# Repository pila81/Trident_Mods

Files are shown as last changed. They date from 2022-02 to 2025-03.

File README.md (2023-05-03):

# Trident Mods

Some modifications and add-ons for the Voron Trident.  

[**AB Stepper Mounts Pin Bearing**](AB_Stepper_Mounts_Pin_Bearing/)  
Trident AB stepper mounts using pins for the idler assemblies and bearings to support the stepper shafts.
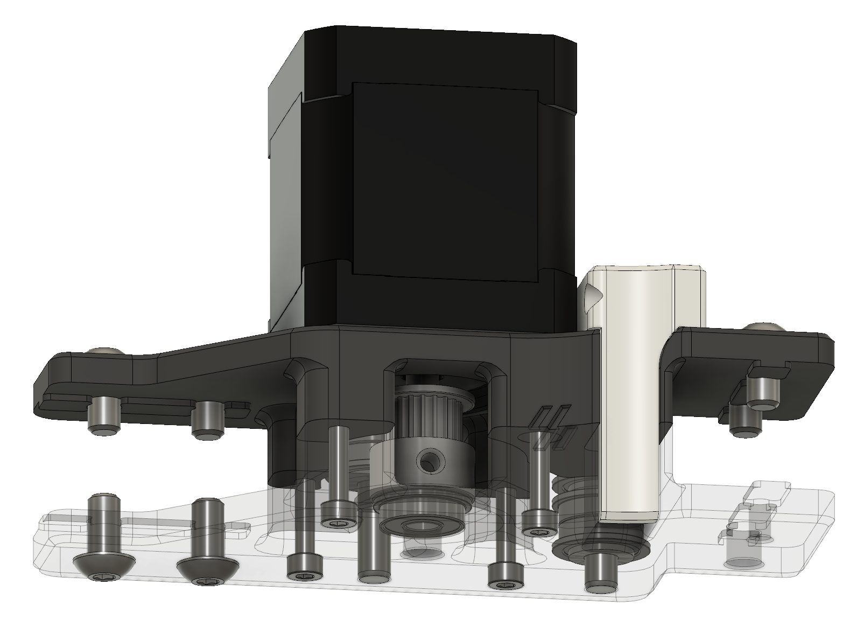
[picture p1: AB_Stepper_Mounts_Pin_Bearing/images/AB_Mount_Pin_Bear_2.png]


[**Idlers Tensioners Aligned**](Idlers_Tensioners_Aligned/)  
Trident front idlers with tensioners aligned to bearings.  
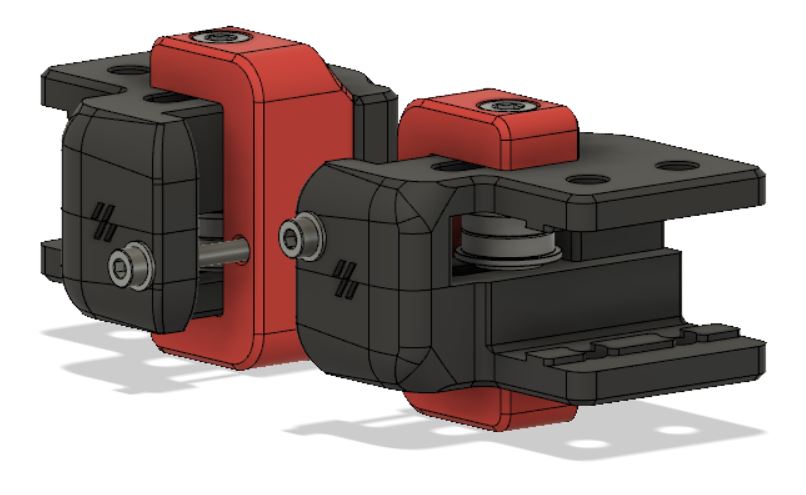
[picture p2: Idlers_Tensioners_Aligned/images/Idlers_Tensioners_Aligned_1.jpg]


[**Exhaust HEPA Filter**](Exhaust_HEPA_Filter/)  
HEPA filter mount for the original exhaust housing.  
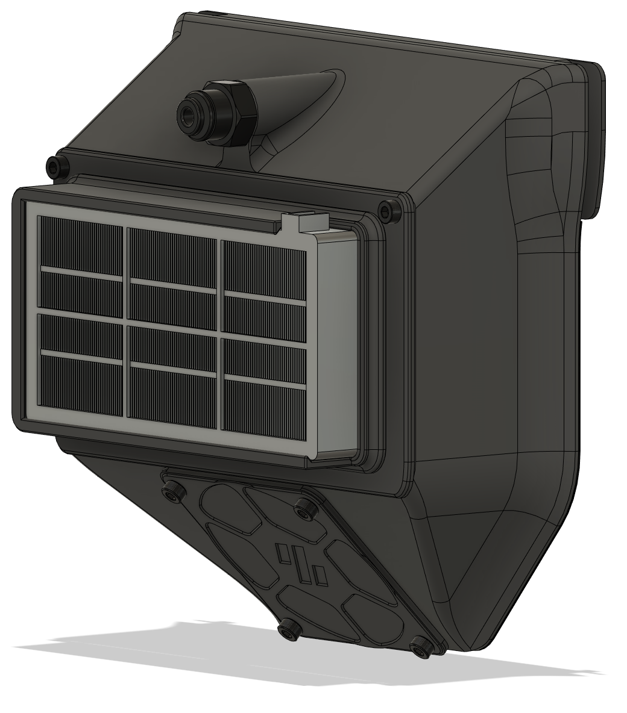
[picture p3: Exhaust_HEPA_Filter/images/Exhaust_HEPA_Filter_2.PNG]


[**Small Exhaust HEPA Filter**](Exhaust_HEPA_Filter_Small/)  
Smaller exhaust housing with HEPA filter mount.  
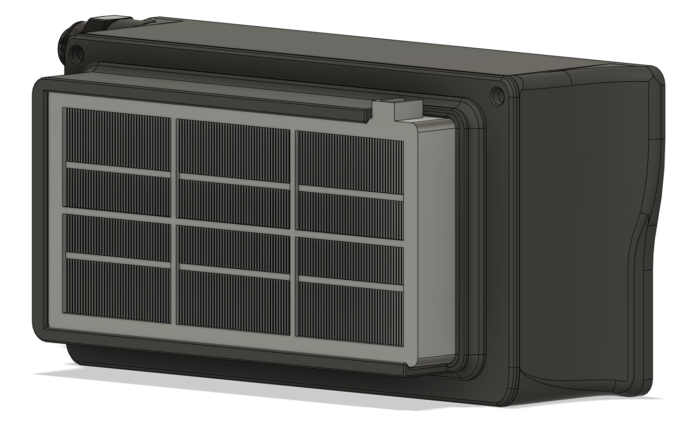
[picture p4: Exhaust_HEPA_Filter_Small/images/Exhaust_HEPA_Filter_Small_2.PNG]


[**Blind Joint Corner Plug**](Blind_Joint_Corner_Plug/)  
Covers the blind joint holes in the top corners of the 2020 extrusions.  
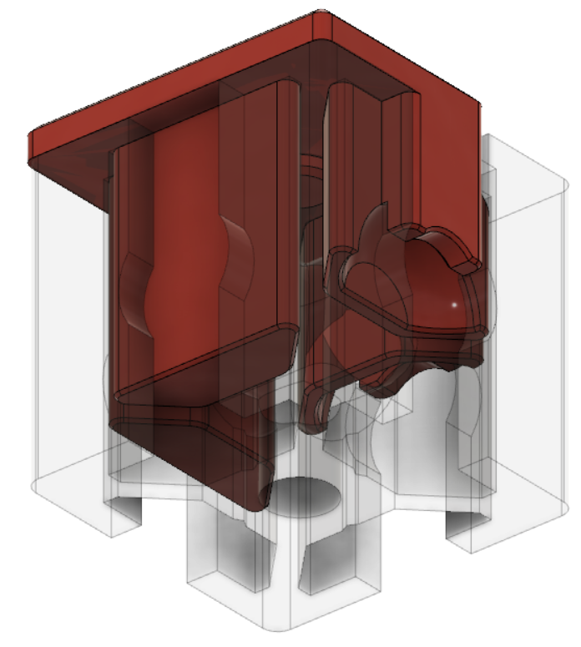
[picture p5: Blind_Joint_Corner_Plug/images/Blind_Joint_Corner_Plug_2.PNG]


[**DIN Rail ZIP Mount**](DIN_Rail_ZIP_Mount/)  
Clip-on DIN rail mount for zip ties/tie wraps.  
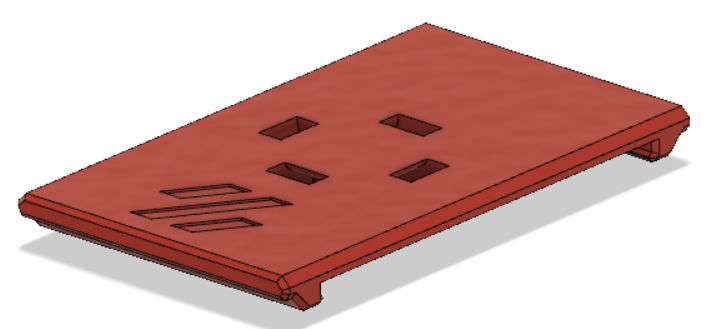
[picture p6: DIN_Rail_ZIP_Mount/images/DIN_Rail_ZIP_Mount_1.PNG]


[**Microfit_2020_Mount_1x2**](Microfit_2020_Mount_1x2/)  
A mount for attaching a 1x2 Microfit plug to a 2020 extrusion.  
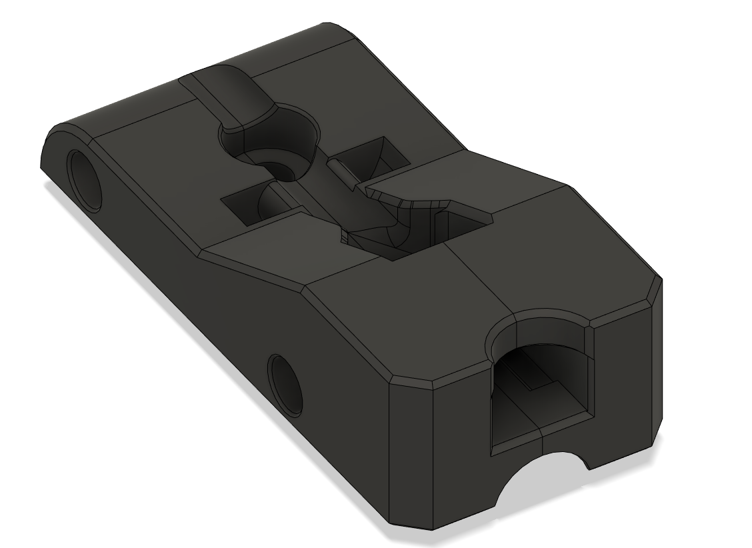
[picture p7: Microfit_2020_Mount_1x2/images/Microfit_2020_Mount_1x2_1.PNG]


[**Z Carriages FLEX**](Z_Carriages_FLEX/)  
Z carriages using a compliant spring mechanism to cope with leadscrew wobble.  
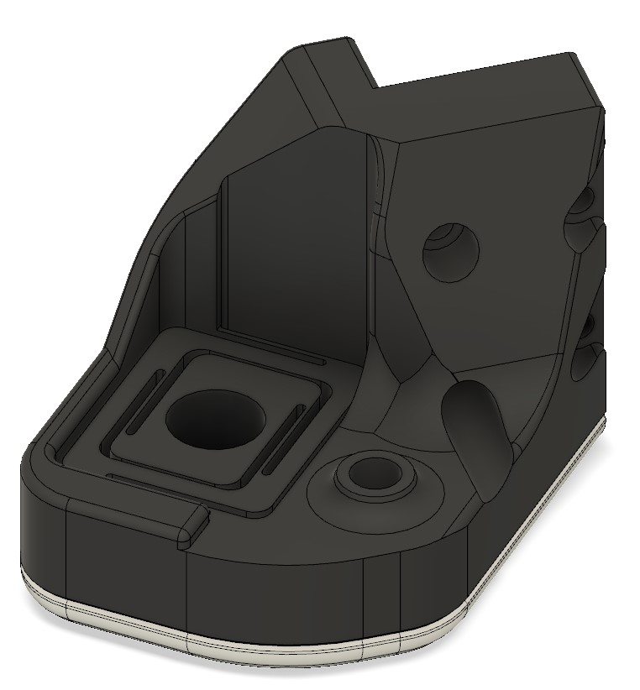
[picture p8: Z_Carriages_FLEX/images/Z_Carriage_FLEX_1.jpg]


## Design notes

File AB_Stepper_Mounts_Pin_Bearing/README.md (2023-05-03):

# AB Stepper Mounts Pin Bearing

**Trident AB Stepper Mounts using pins and bearings**

Trident AB stepper mounts using 5x30 mm pins for the idler assemblies and F695 bearings to support the stepper shafts.

Disclaimer: Only tested this on my printer, use at your own risk.

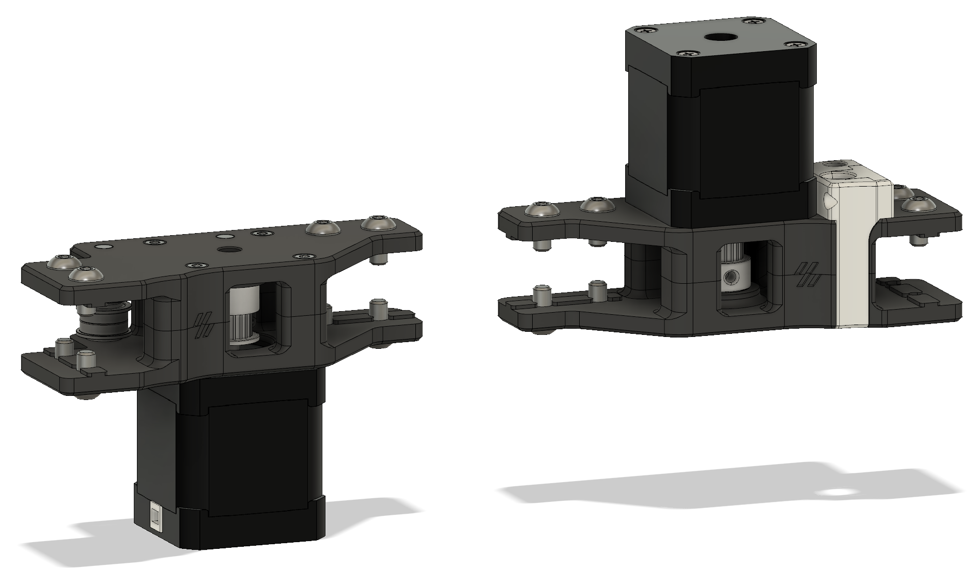
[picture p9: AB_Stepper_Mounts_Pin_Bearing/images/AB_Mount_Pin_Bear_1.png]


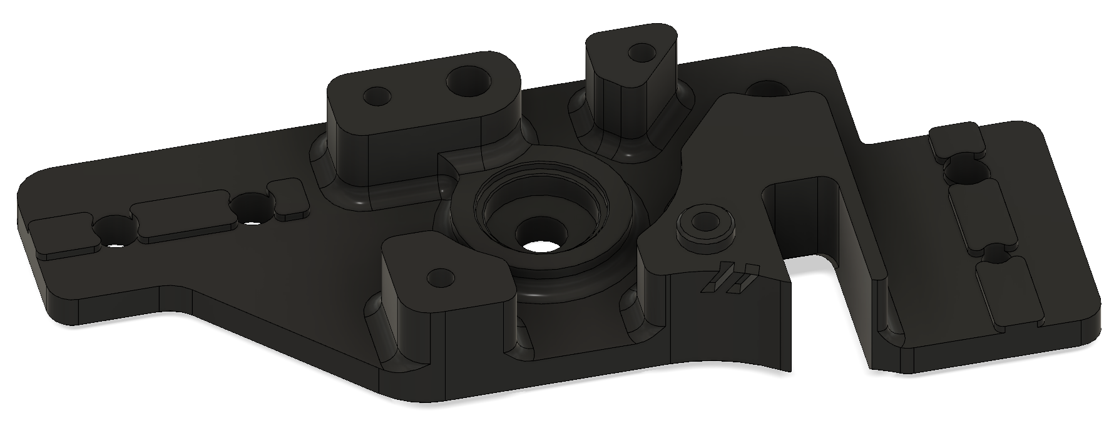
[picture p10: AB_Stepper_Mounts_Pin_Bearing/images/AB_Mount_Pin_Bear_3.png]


Credits for the original stepper mount design go to the Voron team 
https://vorondesign.com/

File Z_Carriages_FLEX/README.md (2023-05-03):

# Z Carriages FLEX

**Trident Z carriages with a printed compliant spring mechanism**

Trident Z carriages with a printed compliant spring mechanism to allow for some leadscrew wobble. 
Top leadscrew mounts (with F688 bearings) are optional, but Z is more accurate with them in my case.
Inspired by ortho-planar spring behavior studies.

2 heatset inserts go into the bottom of each carriage. The leadscrew nut is attached using 2 M3x8 screws with the spacer in between.

Disclaimer: Only tested this on my printer, use at your own risk.


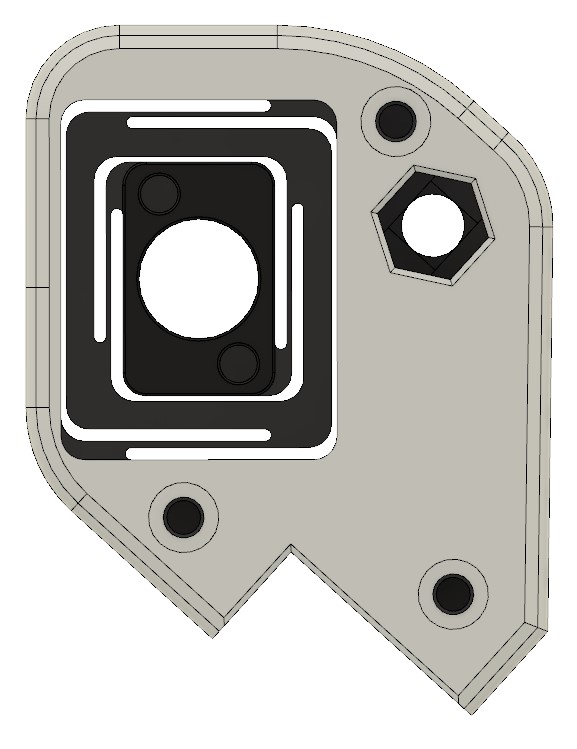
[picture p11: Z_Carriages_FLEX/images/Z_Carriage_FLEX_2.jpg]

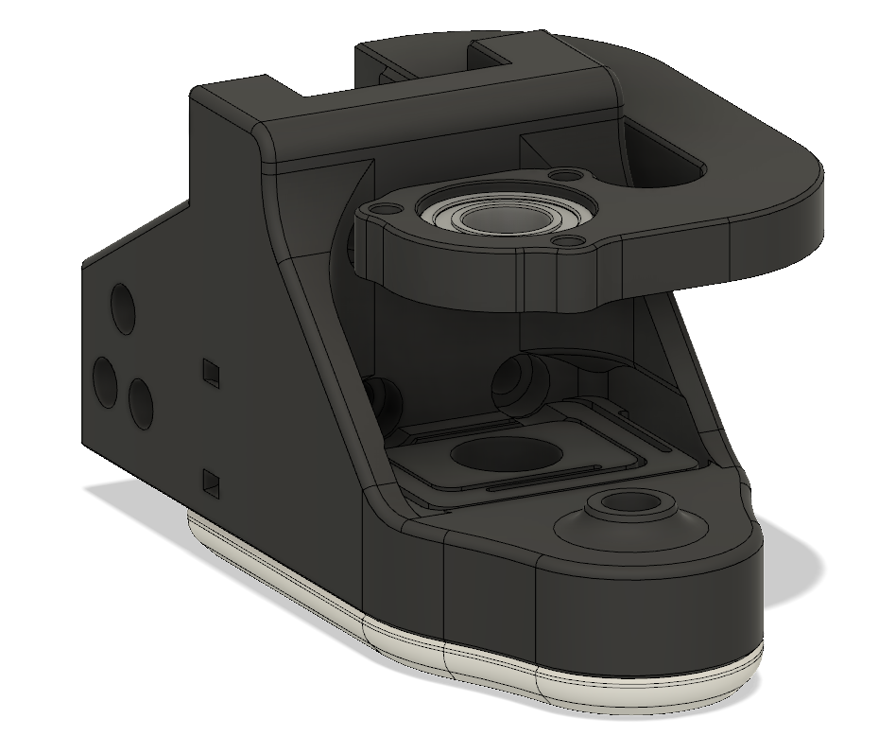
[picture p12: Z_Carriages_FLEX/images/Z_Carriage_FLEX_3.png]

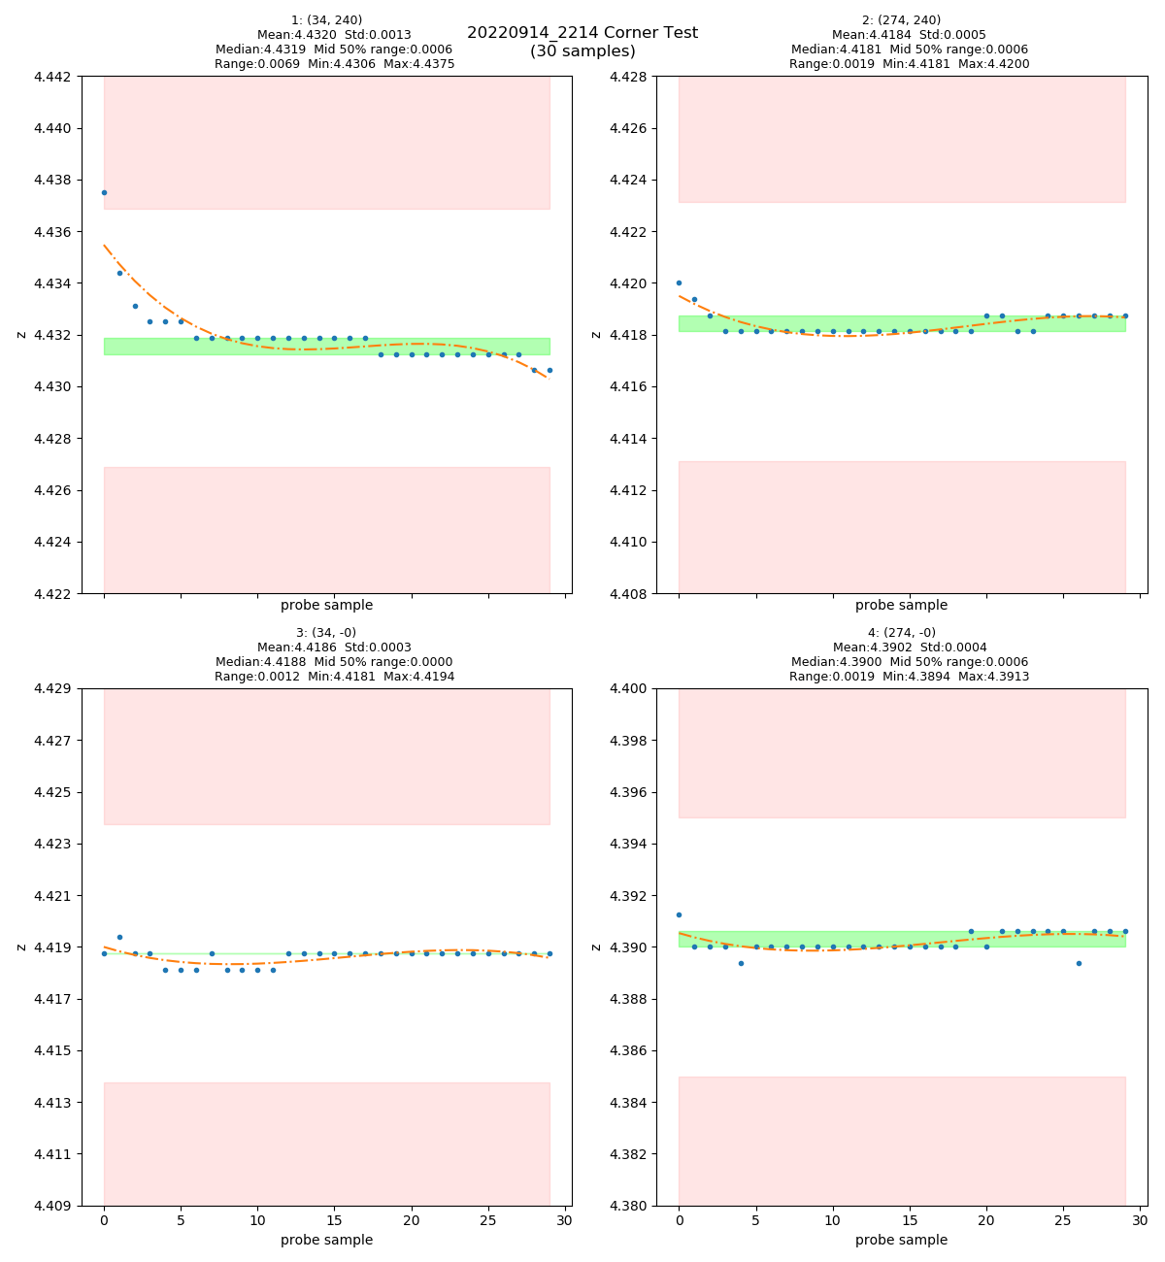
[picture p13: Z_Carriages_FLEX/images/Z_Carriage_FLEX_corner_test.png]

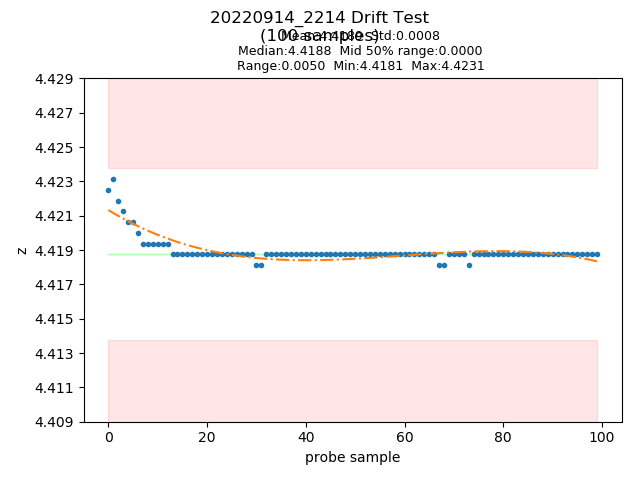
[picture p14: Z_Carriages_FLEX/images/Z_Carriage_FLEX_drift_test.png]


Credits for the original Z carriage design go to the Voron team 
https://vorondesign.com/

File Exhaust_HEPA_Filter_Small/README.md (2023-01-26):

# Small Exhaust HEPA Filter

**Small Voron Trident exhaust using a Roomba 800/900 series HEPA filter**  
With the Nevermore installed to address the VOC inside of the chamber, the next step was an easy to replace HEPA filter to collect the UFP when venting the chamber after a print completes. Had some Roomba HEPA filters laying around so made a fan/filter mount to fit the original exhaust. Two 6020 fans push the chamber air out through the filter.
This is a minimalistic redesign of the original exhaust to just fit the 6020 fans and filter mount.

**Easy maintenance**  
The filter can be slid in and out from the outside of the exhaust, no screws. The foam edge on these filters makes a good seal and a tight fit.

**Modular design**  
As the filter holder is a separate part this can be redesigned for other HEPA filters.

**Other advantages**  
The wiring for the fans can be internally routed through the exhaust grill, so no wires on the outside of your printer.  
No fingers can be harmed by spinning fan blades.

**BOM**
- 1x Roomba 800/900 series HEPA filter
- 2x 6020 fan
- 7x M3 heat inserts
- 7x M3 x 30 bolts

**To print**
- Exhaust_Housing_Small.stl
- Fan_Mount.stl
- Filter_Holder.stl

**Installation**  
First insert the fan mount into the housing, then attach the filter cover and fans. The depth of the mounted fans prevents the fan/filter assembly from tilting into the housing. 

**Notes**  
For a HEPA filter mod for the original exhaust look here: https://github.com/pila81/Trident_Mods/tree/main/Exhaust_HEPA_Filter  
A fan wire connector extrusion mount can be found here: https://github.com/pila81/Trident_Mods/tree/main/Microfit_2020_Mount_1x2  

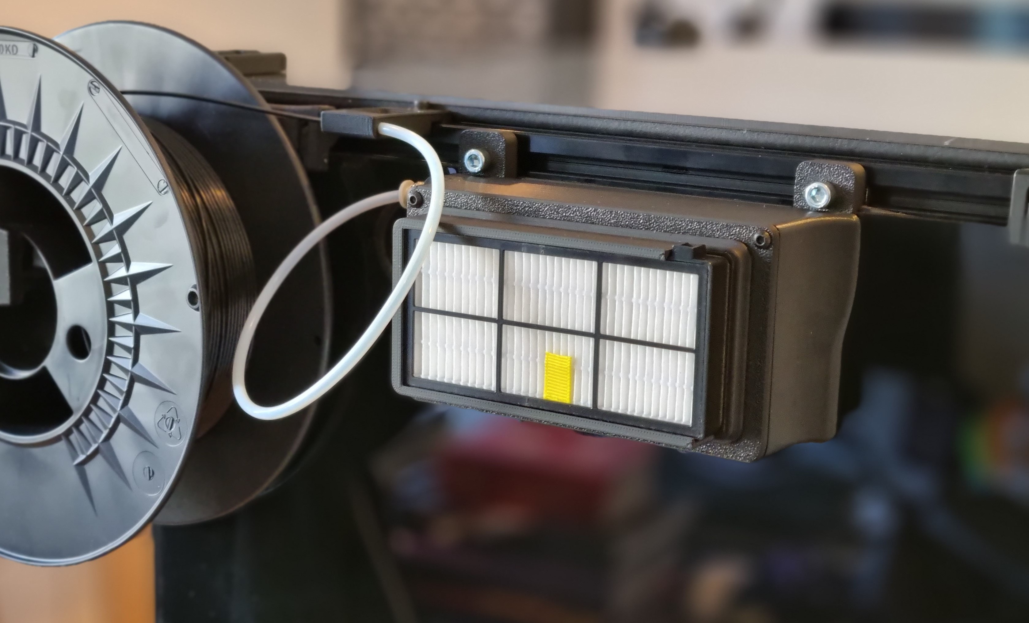
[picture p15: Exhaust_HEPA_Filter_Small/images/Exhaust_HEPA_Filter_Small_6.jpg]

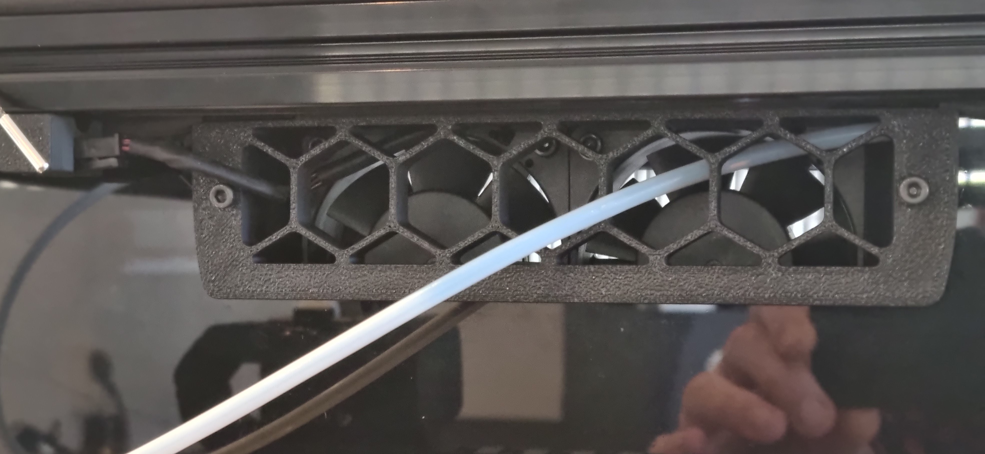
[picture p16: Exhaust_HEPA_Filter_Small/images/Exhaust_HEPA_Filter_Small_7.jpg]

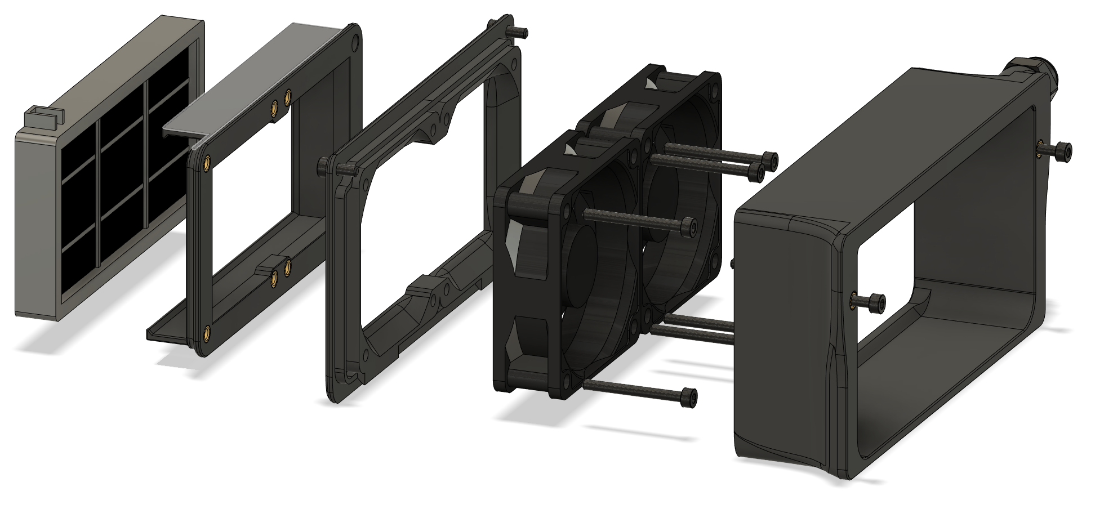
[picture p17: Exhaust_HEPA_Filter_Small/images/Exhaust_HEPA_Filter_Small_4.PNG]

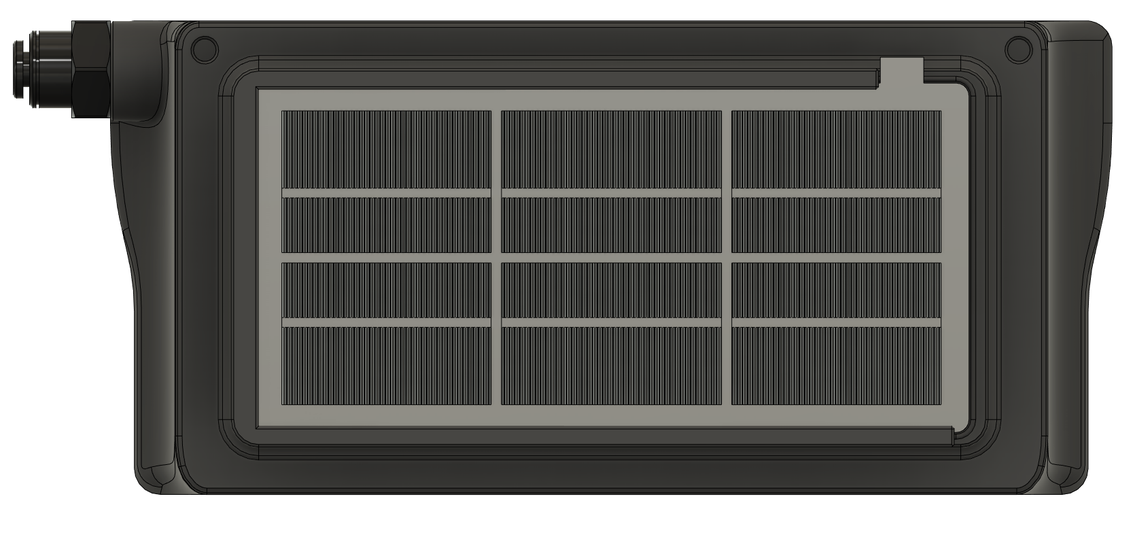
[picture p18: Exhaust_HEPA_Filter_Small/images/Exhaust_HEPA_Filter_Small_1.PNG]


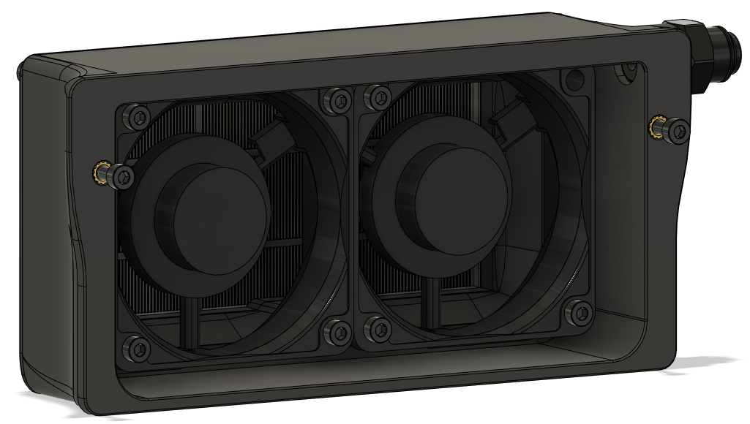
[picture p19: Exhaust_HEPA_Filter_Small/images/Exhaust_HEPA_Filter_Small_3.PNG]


**Small vs original exhaust housing**  
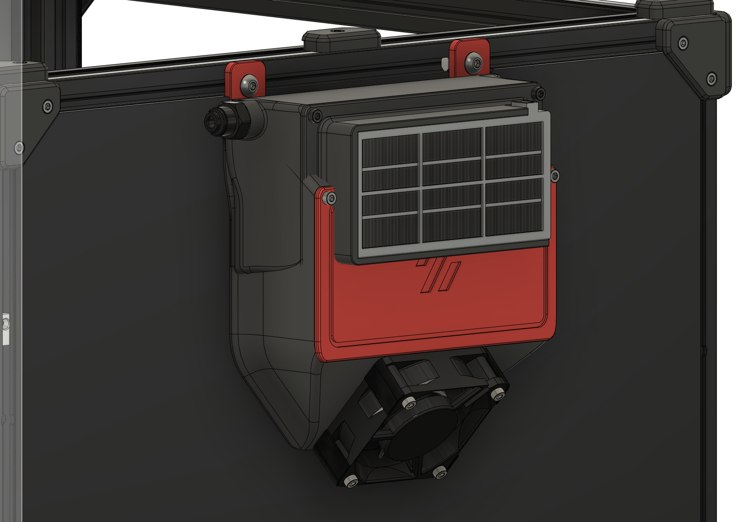
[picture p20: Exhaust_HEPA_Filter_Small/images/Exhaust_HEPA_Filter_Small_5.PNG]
  

Credits for the original exhaust go to the Voron team: https://vorondesign.com/

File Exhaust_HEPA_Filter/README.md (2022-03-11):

# Exhaust HEPA Filter

**Voron Trident exhaust using a Roomba 800/900 series HEPA filter**  
With the Nevermore installed to address the VOC inside of the chamber, the next step was an easy to replace HEPA filter to collect the UFP when venting the chamber after a print completes. Had some Roomba HEPA filters laying around so made a fan/filter mount to fit the original exhaust. Two 6020 fans push the chamber air out through the filter.

**Easy maintenance**  
The filter can be slid in and out from the outside of the exhaust, no screws. The foam edge on these filters makes a good seal and a tight fit.

**Modular design**  
As the filter holder is a seperate part this can be redesigned for other HEPA filters.

**Other advantages**  
The wiring for the fans can be internally routed through the exhaust grill, so no wires on the outside of your printer.  
No fingers can be harmed by spinning fan blades.

**BOM**
- 1x Roomba 800/900 series HEPA filter
- 2x 6020 fan
- 8x M3 heat inserts
- 8x M3 x 30 bolts
- 4x M3 x 6/8/10/12 bolts for the fan hole cover

**To print**
- Fan_Mount.stl
- Filter_Holder.stl
- Fan_Hole_Cover-v?.stl (choose either v1 or v2)

**Installation**  
Installing this assembly in the original exhaust housing while mounted is a tight fit, but it can be done. If this doesn't work for you: remove the exhaust housing, insert the fan mount into the housing, then attach the filter cover and fans.

**Notes**  
For a smaller exhaust using this HEPA filter mod look here: https://github.com/pila81/Trident_Mods/tree/main/Exhaust_HEPA_Filter_Small  
A fan wire connector extrusion mount can be found here: https://github.com/pila81/Trident_Mods/tree/main/Microfit_2020_Mount_1x2  

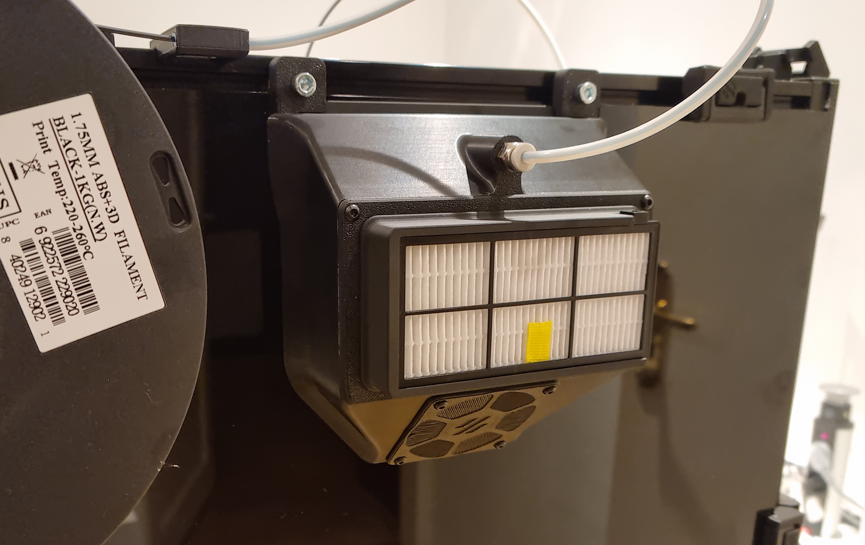
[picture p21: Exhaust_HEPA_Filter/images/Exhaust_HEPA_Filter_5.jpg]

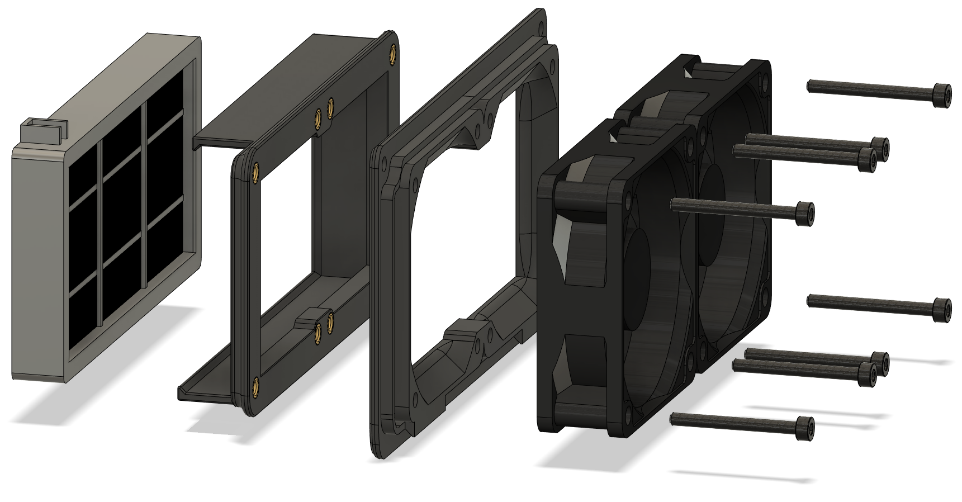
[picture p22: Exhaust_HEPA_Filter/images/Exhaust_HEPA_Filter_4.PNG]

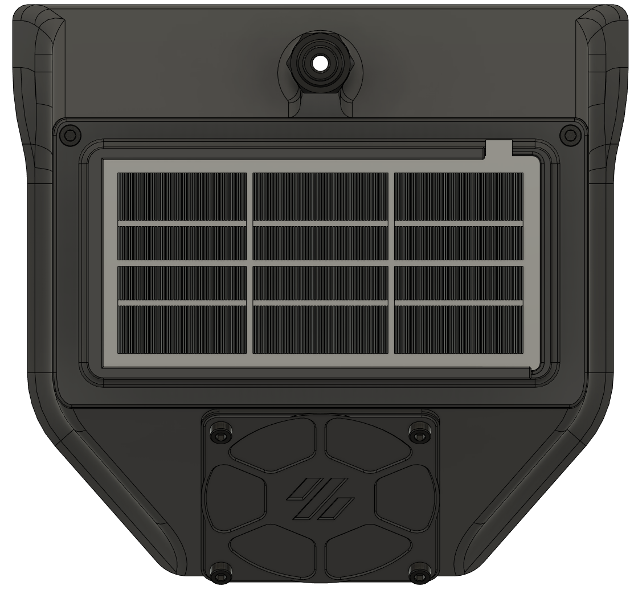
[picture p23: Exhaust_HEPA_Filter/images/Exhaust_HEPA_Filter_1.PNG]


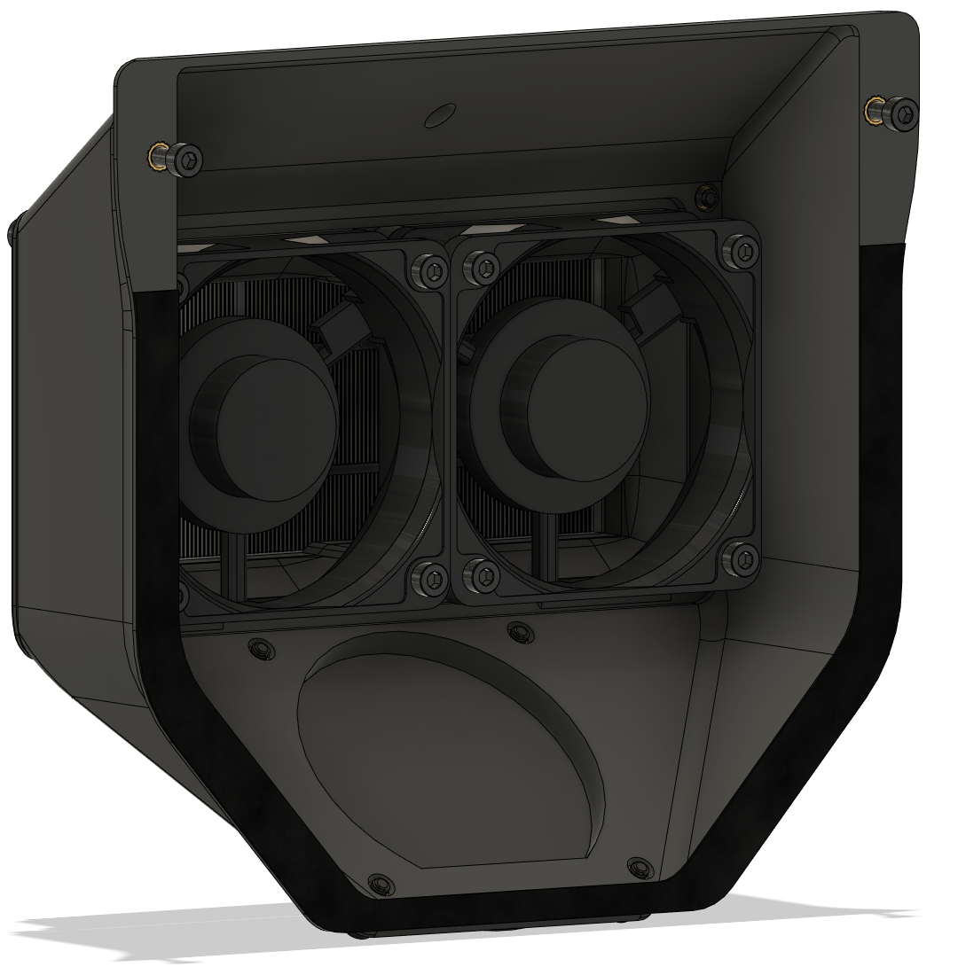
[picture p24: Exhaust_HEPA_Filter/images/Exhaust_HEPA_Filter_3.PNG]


Credits for the original exhaust go to the Voron team: https://vorondesign.com/  
  
Credits for the original design of the 'Fan_Hole_Cover_v2' go to LoganFraser: https://github.com/LoganFraser/VoronMods/tree/main/TridentInvertedElectronics

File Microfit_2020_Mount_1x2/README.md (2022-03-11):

# Microfit 2020 Mount 1x2

A mount for attaching a 1x2 Microfit plug to a 2020 extrusion.

**BOM**
- 2x M2x10 self-tapping screw
- 1x M3x6 or M3x8 button head screw (BHCS) for mounting to the extrusion  


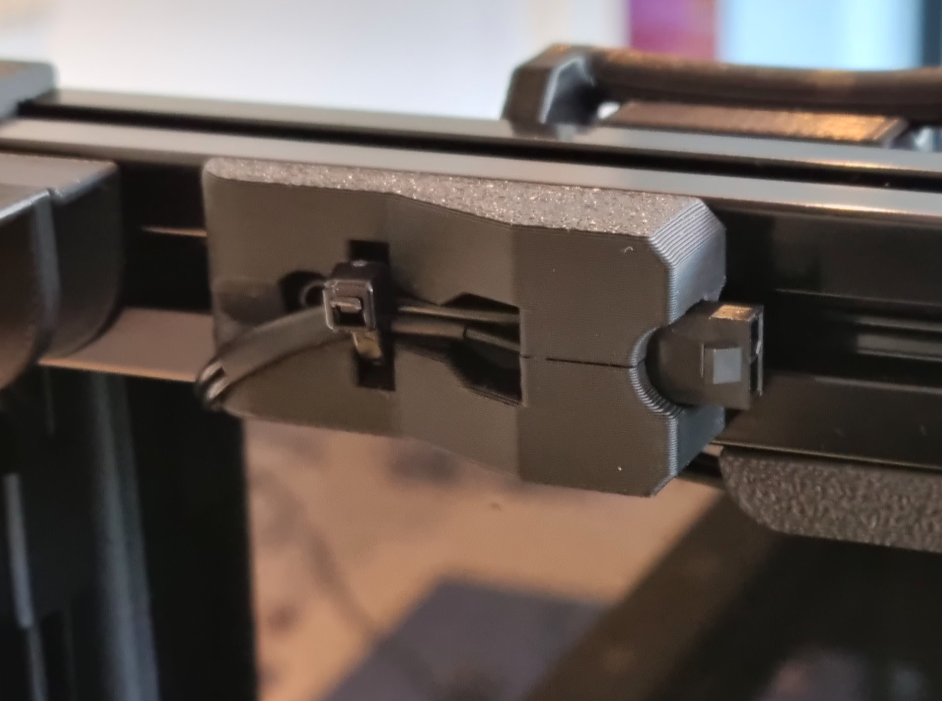
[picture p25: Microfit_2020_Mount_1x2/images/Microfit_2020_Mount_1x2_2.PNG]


Credits for the original design go to samwiseg0  
https://github.com/samwiseg0/VoronUsers/tree/samwiseg0_mods/printer_mods/samwiseg0/ab_plug_microfit_1x4  

Which is derived from Ramalama2's AB Motor Plug  
https://github.com/Ramalama2/Voron-2-Mods/tree/main/AB_Plug_Microfit

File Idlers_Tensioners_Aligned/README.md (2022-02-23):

# Idlers Tensioners Aligned

**Trident front idlers with tensioners aligned to bearings**

Modified front idlers as the idlers/bolts were tilting a bit. In my head aligning the center point of tilt and tension makes sense, they run true now. 
This modification also prevents splitting of the two printed parts, but unfortunately looks less streamlined because the left and right tensioner screws are offset.

Disclaimer: Only tested this on my printer, use at your own risk.

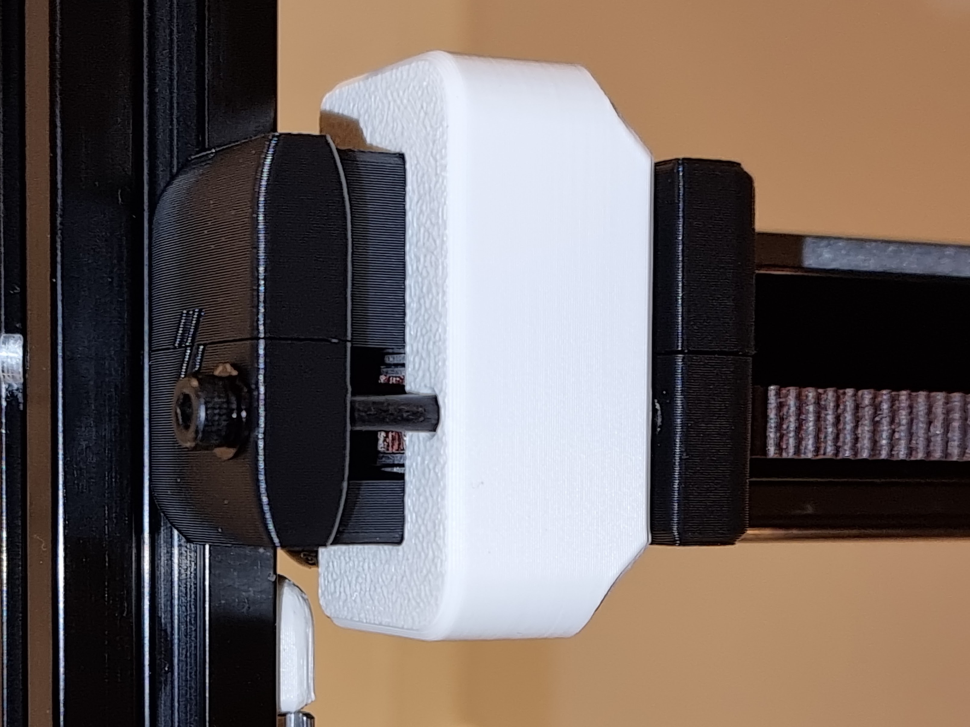
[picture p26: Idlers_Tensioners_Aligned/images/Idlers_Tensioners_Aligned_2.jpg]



All credits to the Voron team 
https://vorondesign.com/

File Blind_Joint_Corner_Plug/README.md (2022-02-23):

# Blind Joint Corner Plug

This plug covers the blind joint holes in the top corners of the 2020 extrusions to better seal the chamber.

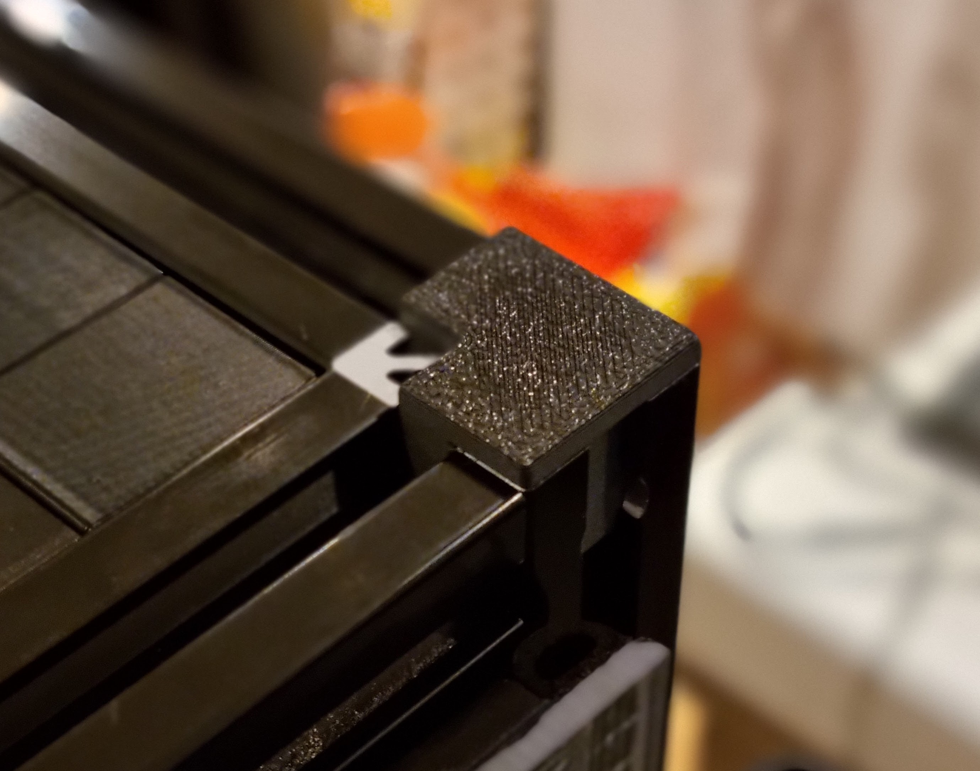
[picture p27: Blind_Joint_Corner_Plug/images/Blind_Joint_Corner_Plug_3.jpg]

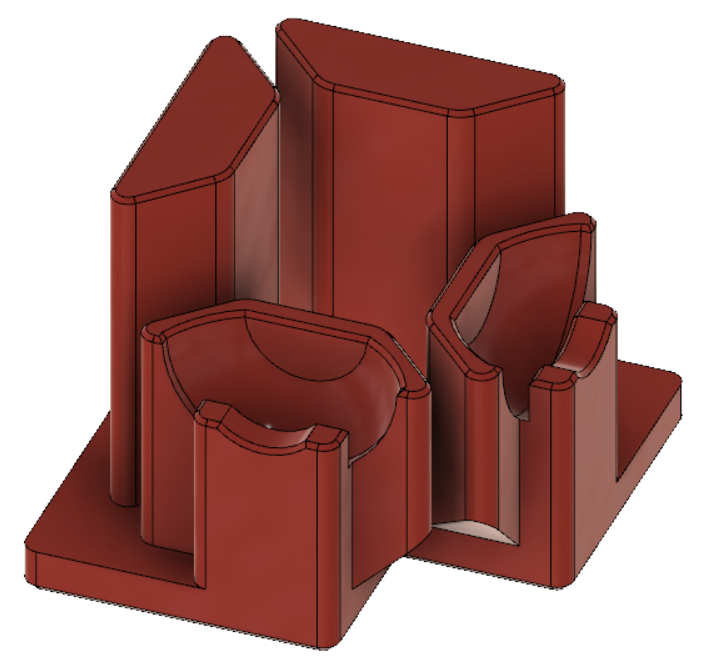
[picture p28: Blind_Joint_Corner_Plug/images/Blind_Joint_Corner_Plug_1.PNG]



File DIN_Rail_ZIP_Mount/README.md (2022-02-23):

# DIN Rail ZIP Mount

Clip-on DIN rail mount for zip ties/tie wraps.

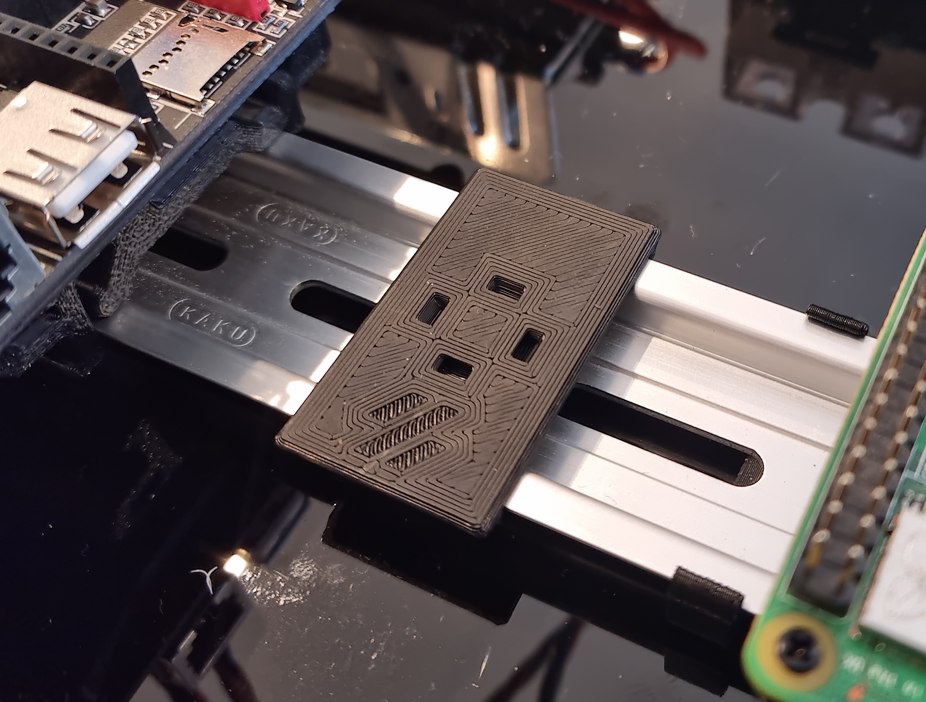
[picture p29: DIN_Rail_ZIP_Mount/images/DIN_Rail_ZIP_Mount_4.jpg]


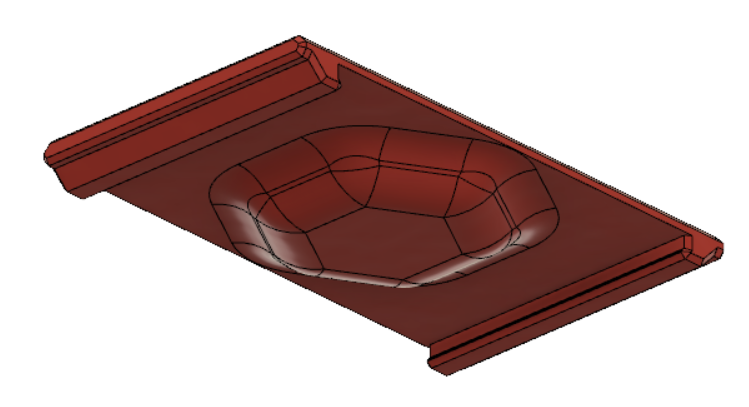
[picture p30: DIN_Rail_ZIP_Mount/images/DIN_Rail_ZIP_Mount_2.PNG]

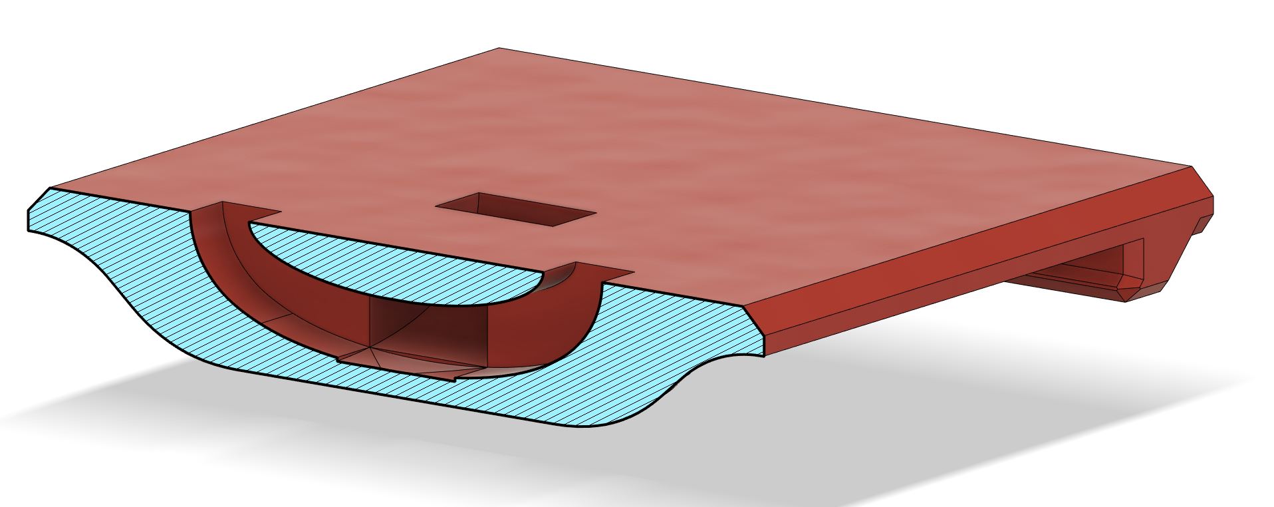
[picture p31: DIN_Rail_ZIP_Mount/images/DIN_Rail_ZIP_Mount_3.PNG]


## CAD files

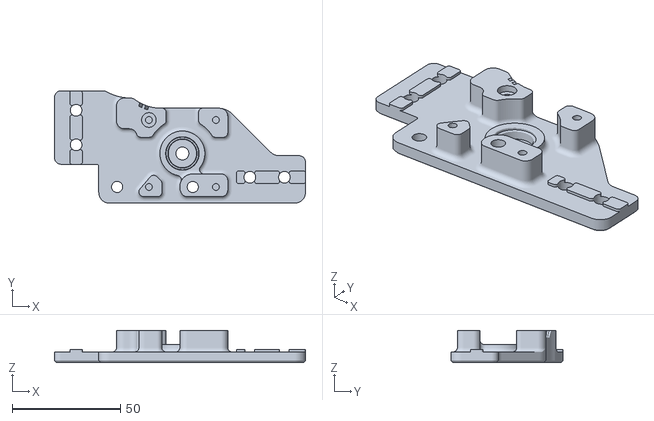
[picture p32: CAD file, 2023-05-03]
AB_Stepper_Mounts_Pin_Bearing/STL/b_drive_frame_upper_pin_bear.stl
116.2 x 52.0 x 15.0

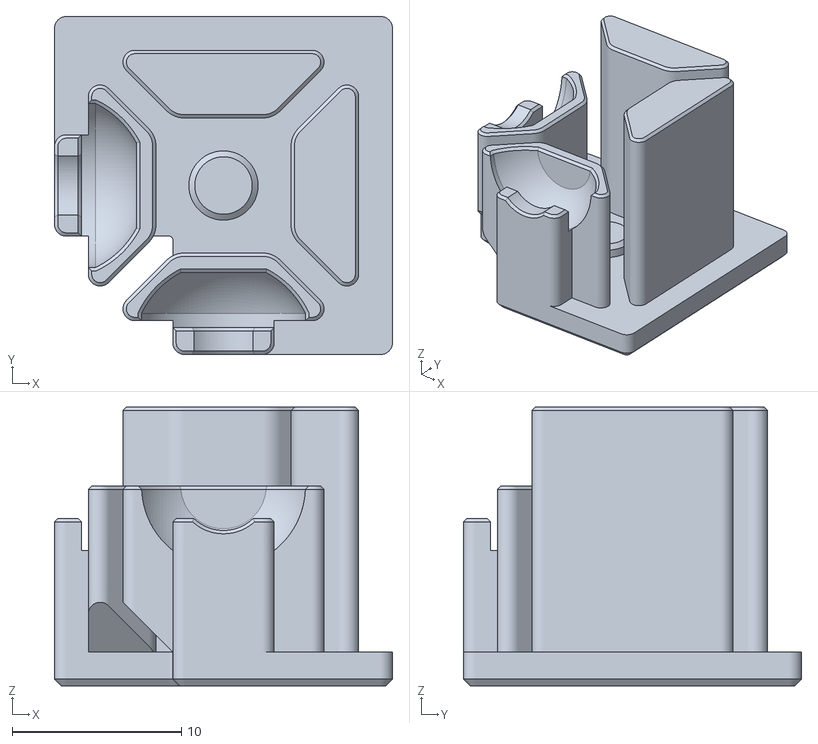
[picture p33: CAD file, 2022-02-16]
Blind_Joint_Corner_Plug/STL/Blind_Joint_Corner_Plug.stl
20.0 x 20.0 x 16.5

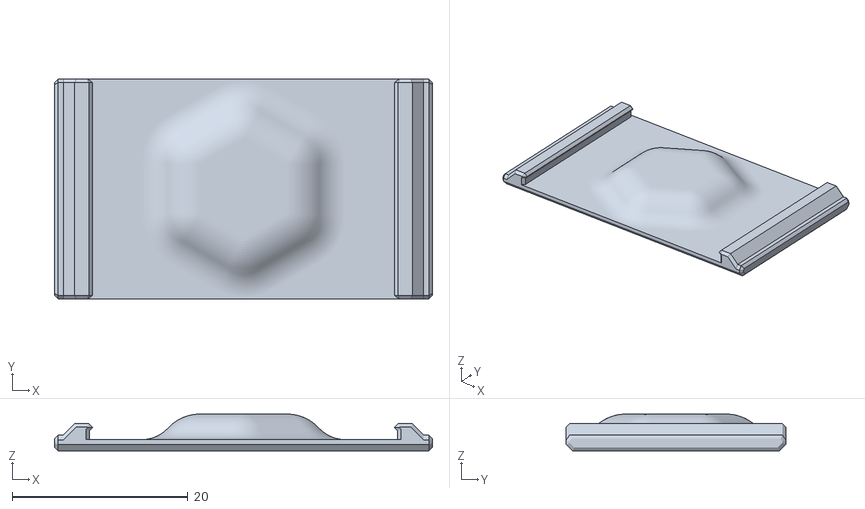
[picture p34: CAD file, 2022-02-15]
DIN_Rail_ZIP_Mount/STL/DIN_Rail_ZIP_Mount.stl
43.0 x 25.0 x 4.20

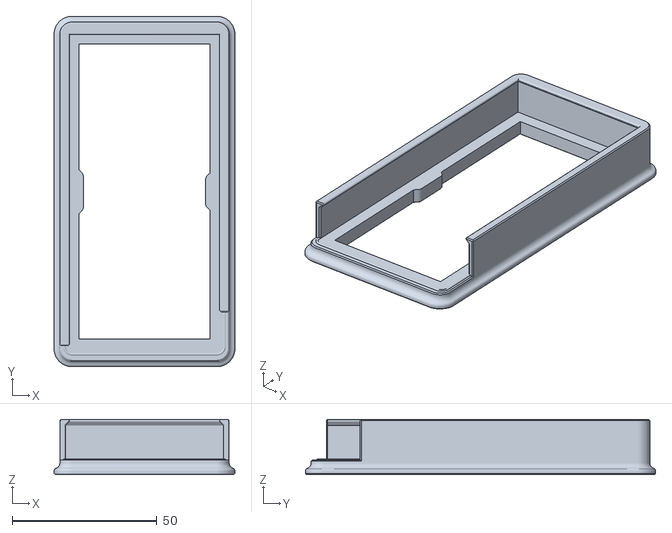
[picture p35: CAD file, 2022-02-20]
Exhaust_HEPA_Filter/STL/Filter_Holder.stl
62.5 x 121.0 x 19.0

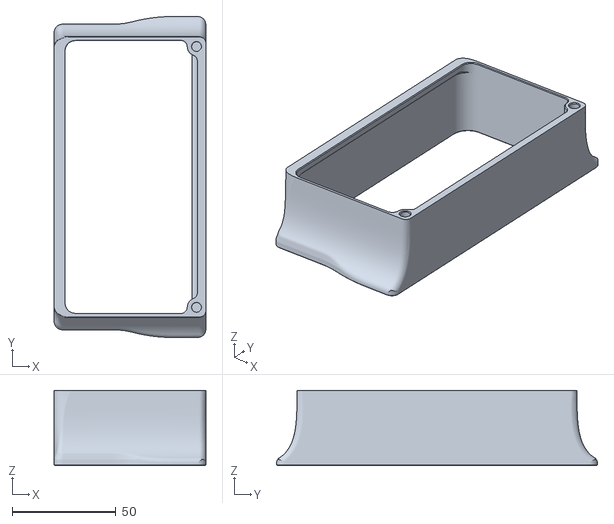
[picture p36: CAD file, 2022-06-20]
Exhaust_HEPA_Filter_Small/STL/Exhaust_Housing_Small_No_PTFE_Inlet.stl
73.2 x 154.8 x 36.3

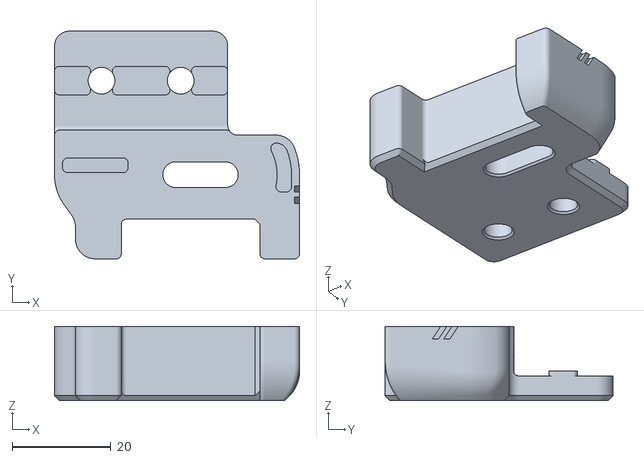
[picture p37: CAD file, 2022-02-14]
Idlers_Tensioners_Aligned/STL/front_idler_b.stl
49.5 x 46.0 x 15.0

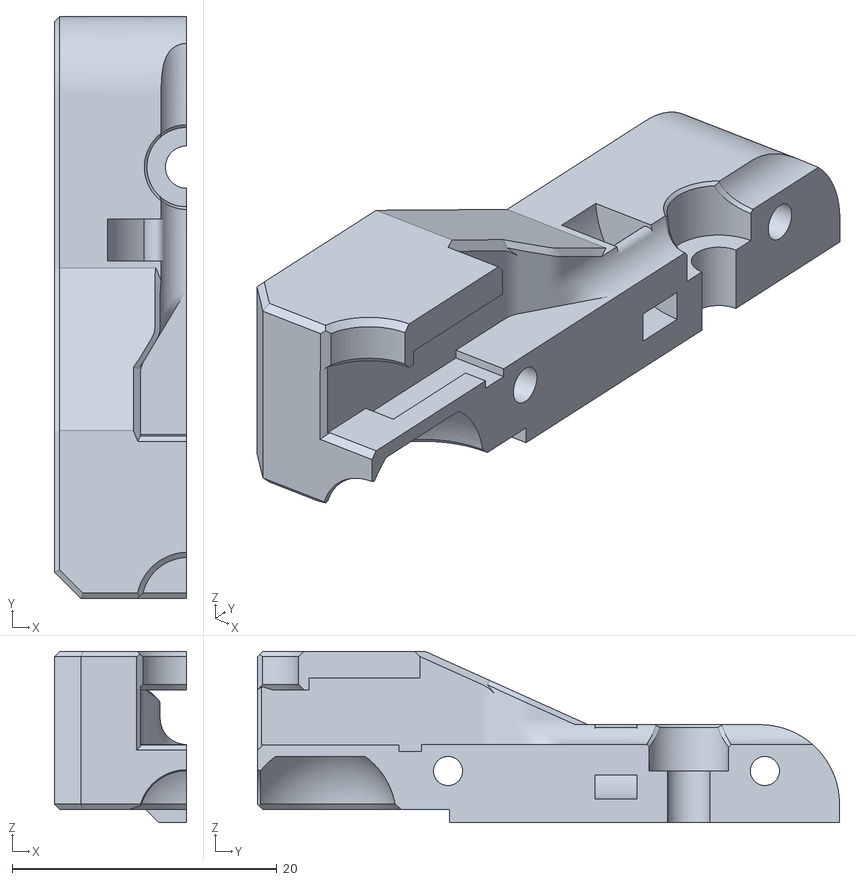
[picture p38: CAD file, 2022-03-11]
Microfit_2020_Mount_1x2/STL/Microfit_2020_Mount_1x2_R.stl
10.0 x 44.0 x 12.9

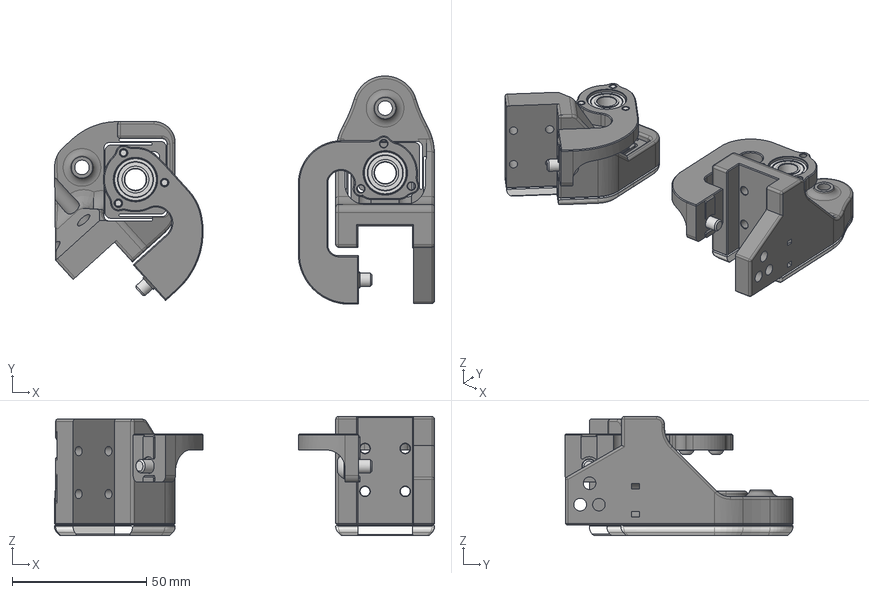
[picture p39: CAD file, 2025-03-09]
Z_Carriages_FLEX/CAD/Trident_Z_Carriages_FLEX v1.step
141.7 x 85.0 x 44.4 mm
z_carriage_left (1)
[a]_z_carriage_left (1)
Spacer
Fixure_Front
F688Z Ball Bearing Flanged v1
M5x10 BHCS (21) (1)
M3x6 BHCS (2)
M3x6 BHCS (2) (2)
M3x6 BHCS (2) (3)
z_carriage_rear_3hole (1)
[a]_z_carriage_rear_3hole (1)
Spacer (1)
Fixure_Back
M5x10 BHCS (21) (1) (1)
F688Z Ball Bearing Flanged v1 (1)

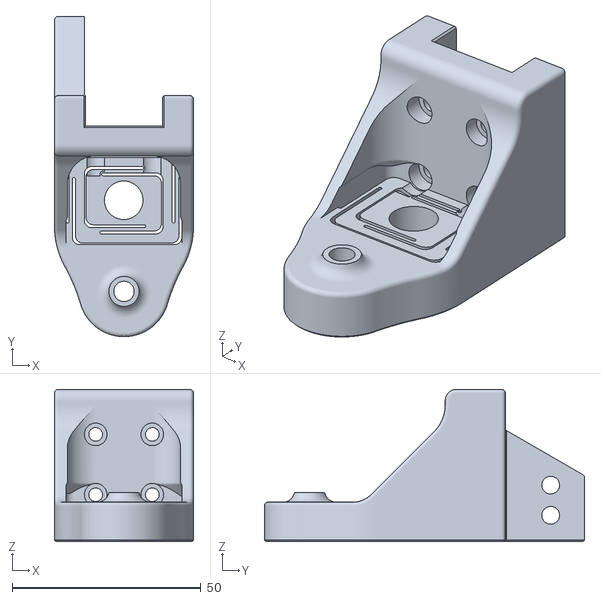
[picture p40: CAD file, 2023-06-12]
Z_Carriages_FLEX/STL/z_carriage_rear_2hole_FLEX.stl
36.8 x 84.9 x 40.4

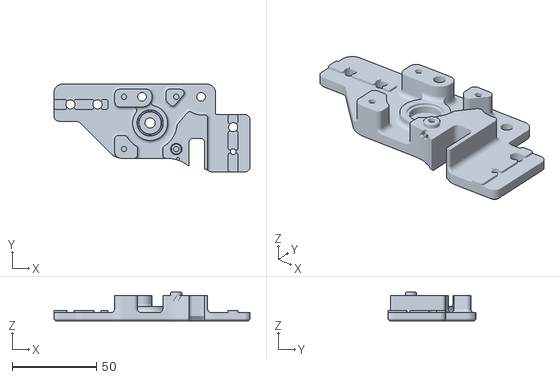
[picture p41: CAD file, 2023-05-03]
AB_Stepper_Mounts_Pin_Bearing/STL/a_drive_frame_lower_pin_bear.stl
116.2 x 52.0 x 17.0

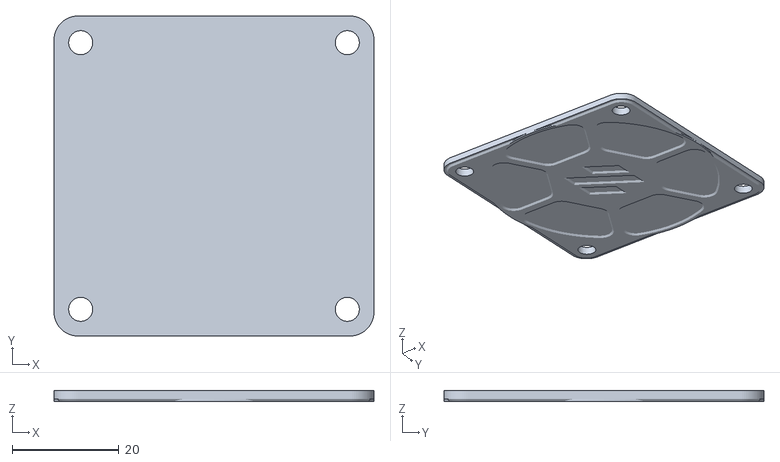
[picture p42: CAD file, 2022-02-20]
Exhaust_HEPA_Filter/STL/Fan_Hole_Cover_v2.stl
60.0 x 60.0 x 2.00

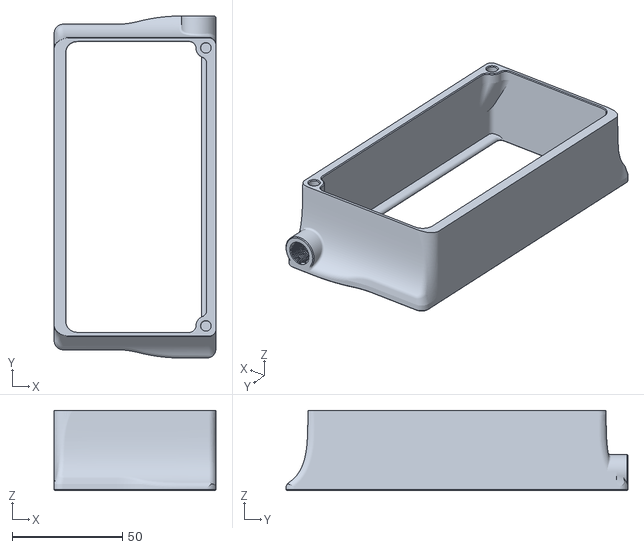
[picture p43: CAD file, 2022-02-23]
Exhaust_HEPA_Filter_Small/STL/Exhaust_Housing_Small.stl
73.2 x 154.8 x 36.3

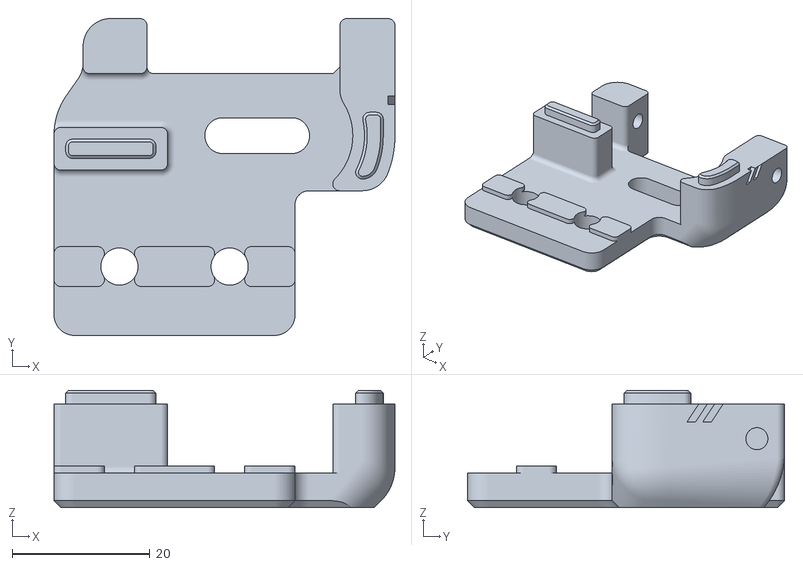
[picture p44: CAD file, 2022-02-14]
Idlers_Tensioners_Aligned/STL/front_idler_a.stl
49.5 x 46.0 x 17.0

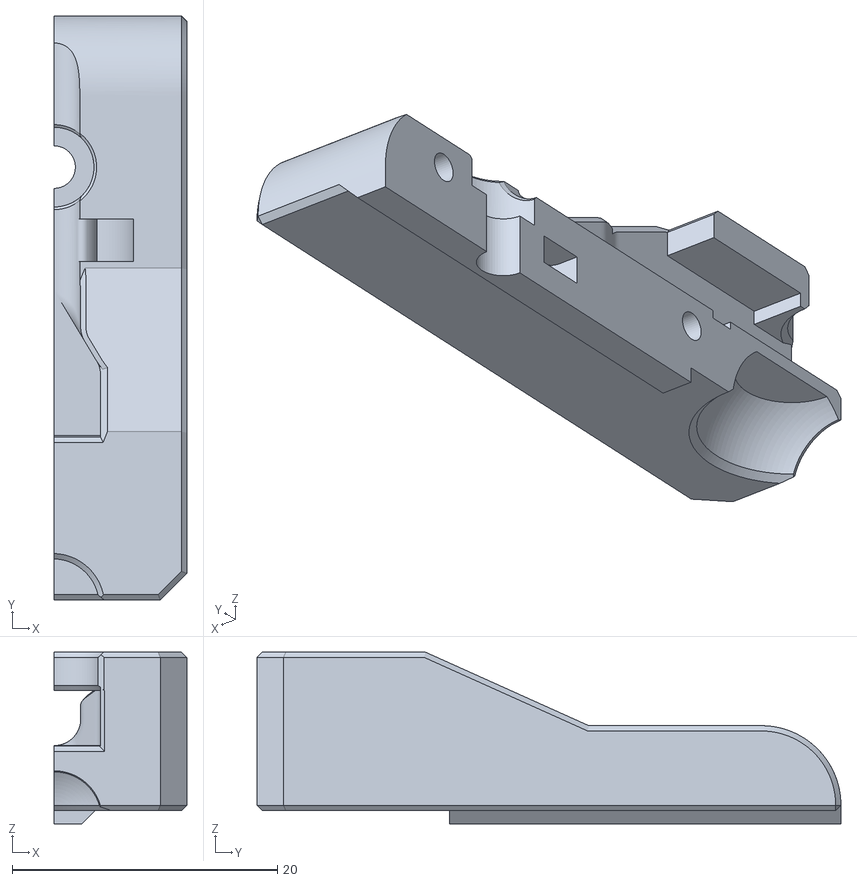
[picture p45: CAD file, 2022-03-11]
Microfit_2020_Mount_1x2/STL/Microfit_2020_Mount_1x2_L.stl
10.00 x 44.0 x 12.9

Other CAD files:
Z_Carriages_FLEX/STL/z_carriage_rear_spacer_FLEX.stl
AB_Stepper_Mounts_Pin_Bearing/STL/a_drive_frame_upper_pin_bear.stl
Idlers_Tensioners_Aligned/STL/[a]_tensioner_left.stl
AB_Stepper_Mounts_Pin_Bearing/STL/b_drive_frame_lower_pin_bear.stl
Blind_Joint_Corner_Plug/CAD/Blind_Joint_Corner_Plug.f3d
DIN_Rail_ZIP_Mount/CAD/DIN_Rail_ZIP_Mount.f3d
Exhaust_HEPA_Filter/STL/Fan_Hole_Cover_v1.stl
Exhaust_HEPA_Filter_Small/STL/Fan_Mount.stl
Idlers_Tensioners_Aligned/CAD/Idlers_Tensioners_Aligned.f3d
Idlers_Tensioners_Aligned/STL/[a]_tensioner_right.stl
Microfit_2020_Mount_1x2/CAD/Microfit_2020_Mount_1x2.f3d
Z_Carriages_FLEX/CAD/Trident_Z_Carriages_FLEX.f3d
Z_Carriages_FLEX/STL/[a]z_carriage_left_FLEX.stl
Z_Carriages_FLEX/STL/[a]z_carriage_rear_3hole_FLEX.stl
Z_Carriages_FLEX/STL/[a]z_carriage_right_FLEX.stl
Z_Carriages_FLEX/STL/z_carriage_left_FLEX.stl
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

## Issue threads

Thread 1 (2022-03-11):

Fan Wiring

rrik, 2022-03-11:
What is the extrusion mount that you are connecting the fan wiring to? Is this with a 2x2 molex?

pila81, 2022-03-11:
My fan wires are crimped together in the microfit pins so I'm using a 1x2 microfit plug.
The extrusion mount is a modified version of samwiseg0's Microfit AB Plug (which is derived from Ramalama2's AB Motor Plug).
I've added it to my repo for your convenience: https://github.com/pila81/Trident_Mods/tree/main/Microfit_2020_Mount_1x2
There are links to the original designs in there.

Closed 2022-03-12.

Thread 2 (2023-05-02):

Question: Z Carriages FLEX - Nut Mount?

JanB97, 2023-05-02:
I would like to try your bed mount, but I am not sure how the cariage is mounted to the leadscrew.
Do you put heatset inserts and use m3 screws? also does the spacer go between cariage and nut?

pila81, 2023-05-02:
Yes, 2 heatset inserts go into the bottom of each carriage. The leadscrew nut is attached with M3 screws (8mm I think) with the spacer in between.

JanB97, 2023-05-03:
Thank you!

Closed 2023-05-03.

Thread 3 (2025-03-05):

Can you share CAD?

pasha4ur, 2025-03-05:
Hello

Can you share the CAD file with the top holders, please?

pasha4ur, 2025-03-05:
> What design are you referring to?

This one: https://github.com/pila81/Trident_Mods/tree/main/Z_Carriages_FLEX

pila81, 2025-03-06:
There is a 'CAD' folder containing the Fusion file.

pasha4ur, 2025-03-09:
> There is a 'CAD' folder containing the Fusion file.
Thank you.

Can you, please, export it to a STEP file (universal format)? Fusion isn't available for me and some counties.

pila81, 2025-03-09:
No problem, I added the STEP file anyway for your reference.

Closed 2025-03-11.
